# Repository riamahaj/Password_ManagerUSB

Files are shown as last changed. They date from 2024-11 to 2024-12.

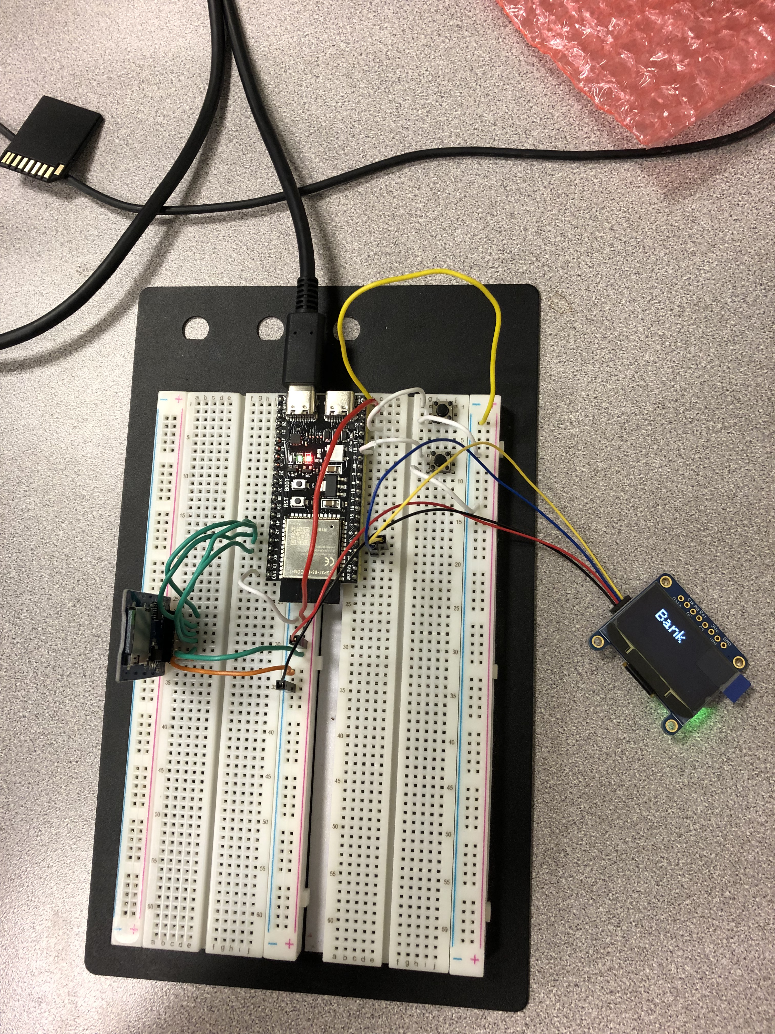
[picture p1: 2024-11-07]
breadboard-proto.jpg

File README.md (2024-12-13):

# Password_ManagerUSB
This repository is for our ECE 411 Password Manager Bank project
It features a MicroSD card reader, an OLED for displaying password websites, and a keypad for scrolling and selecting passwords to output. 
It has 32GB space for extra storage and has encryption features, as well as a webpage that displays websites and passwords with a password strength indicator.





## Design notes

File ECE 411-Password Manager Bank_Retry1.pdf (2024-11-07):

Untitled Gantt Project | Nov 7, 2024 http://

Project manager
Project dates | Oct 10, 2024 - Dec 14, 2024
Completion | 0%
Tasks | 35
Resources | 0

Name | Begin date | End date
1: Creating Project | 10/10/24 | 10/15/24
1.1 Generate 3-5 Project ideas | 10/10/24 | 10/12/24
1.2 Refine Project Ideas | 10/13/24 | 10/13/24
1.3 Select 1 Project | 10/14/24 | 10/14/24
1.4 Set Up a Collaboration Site | 10/14/24 | 10/14/24
1.5 Purchase Components | 10/15/24 | 10/15/24
2: Product Design Specification | 10/17/24 | 10/23/24
2.1 Setting Project Reqiuirements and Concept | 10/17/24 | 10/17/24
2.1 Level 0 and 1 Block Diagrams | 10/18/24 | 10/19/24
2.2 Design Specifications | 10/21/24 | 10/23/24
3: Prototype | 10/24/24 | 11/20/24
3.1 Design Matrix | 10/24/24 | 10/25/24
3.2 AHP Methodologies | 10/26/24 | 10/27/24
3.3 Connect OLED to ESP32 | 10/24/24 | 10/25/24
3.4 Connect MircoSD to ESP32 | 10/26/24 | 10/27/24
3.5 Add 2 buttons | 10/26/24 | 10/26/24
3.6 Preliminary Shematic(KiCAD) | 10/28/24 | 10/29/24
3.7 Test Components | 10/28/24 | 10/30/24
4: Software Implementation | 11/7/24 | 11/16/24
4.1 Read/Write .txt Files | 11/7/24 | 11/11/24
4.1.a Test/Debug | 11/7/24 | 11/11/24
4.2 Implement CVS Files | 11/12/24 | 11/16/24
4.2.a Test/Debug | 11/12/24 | 11/16/24
5. LED UI | 11/11/24 | 11/16/24
5.1 Create User Friendly Menu | 11/11/24 | 11/15/24
5.2 Add Optional Features(If Time permits) | 11/16/24 | 11/16/24
Untitled Gantt Project | Nov 7, 2024
Tasks | 2

Name | Begin date | End date
6: CAD | 11/15/24 | 11/20/24
6.1 Circuit Schemaitc | 11/15/24 | 11/19/24
6.2 Final CAD review | 11/20/24 | 11/20/24
7: Final Product | 11/21/24 | 12/13/24
7.1 Send Final Version of Schematic to EPL | 11/21/24 | 11/26/24
7.2 Pick up Circuit Board | 11/27/24 | 11/27/24
7.3 Assembling | 11/29/24 | 12/1/24
7.4 Test Boards | 12/2/24 | 12/6/24
7.4 Final Product Presentation | 12/9/24 | 12/13/24
Tasks | 3

## Gantt Chart

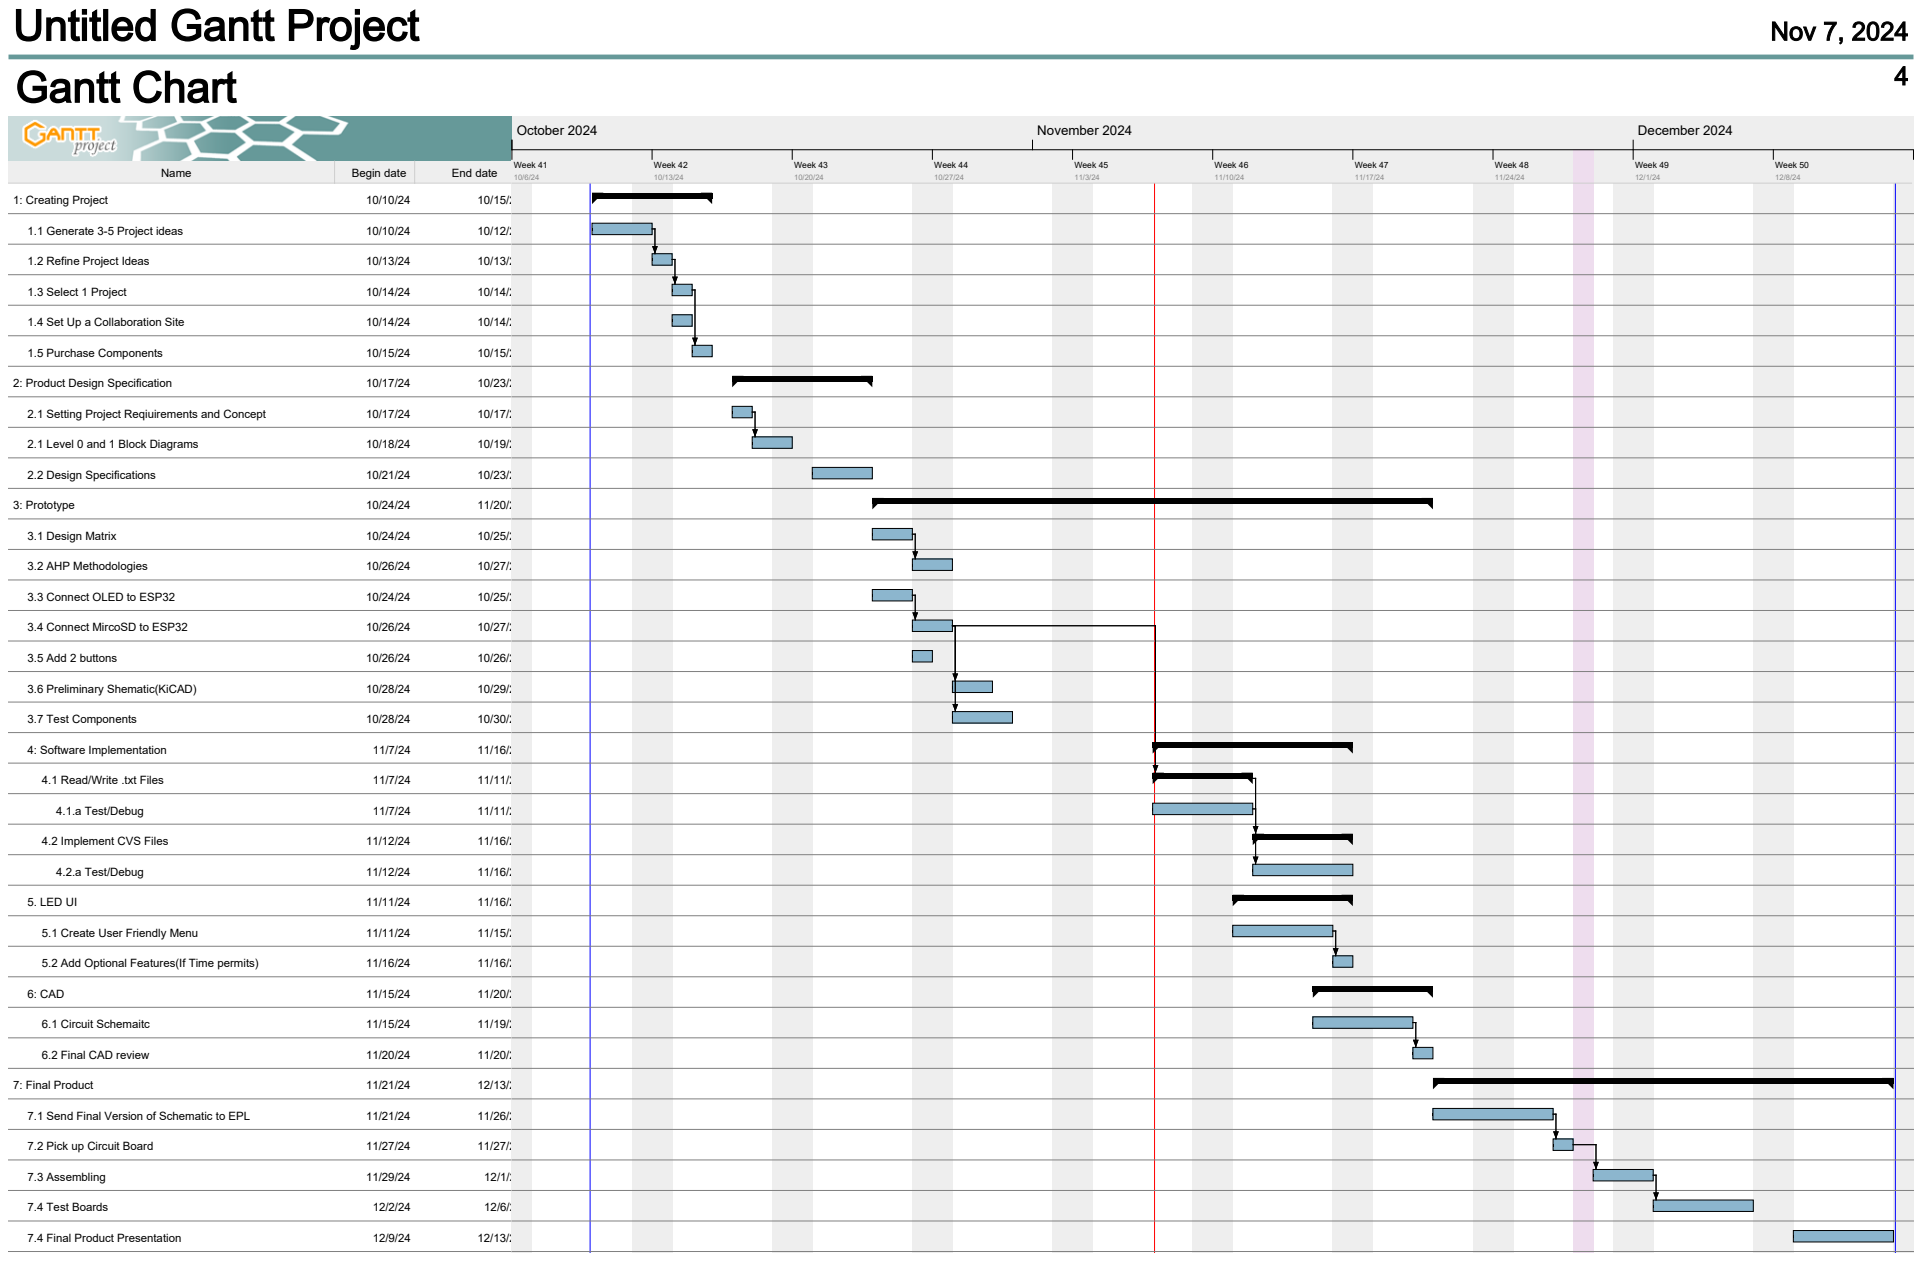
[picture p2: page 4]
Name; Begin date; End date; 1: Creating Project; 1.1 Generate 3-5 Project ideas; 1.2 Refine Project Ideas; 1.3 Select 1 Project; 1.4 Set Up a Collaboration Site; 1.5 Purchase Components; 2: Product Design Specification; 2.1 Setting Project Reqiuirements and Concept; 2.1 Level 0 and 1 Block Diagrams; 2.2 Design Specifications; 3: Prototype; 3.1 Design Matrix; 3.2 AHP Methodologies; 3.3 Connect OLED to ESP32; 3.4 Connect MircoSD to ESP32; 3.5 Add 2 buttons; 3.6 Preliminary Shematic(KiCAD)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

## Resources Chart

5

Name | Default role
October 2024 | November 2024 | December 2024
Week 41 | Week 42 | Week 43 | Week 44 | Week 45 | Week 46 | Week 47 | Week 48 | Week 49 | Week 50
10/6/24 | 10/13/24 | 10/20/24 | 10/27/24 | 11/3/24 | 11/10/24 | 11/17/24 | 11/24/24 | 12/1/24 | 12/8/24

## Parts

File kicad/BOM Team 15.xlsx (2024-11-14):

Bill Of Materials for: TEAM 15
Last modified: 11/13/2024
PCB version: 1
BOM revision: 3 |  | P/NP | = Place/Not Place (components marked NP are not stuffed on the board)
Cnt | Part References | P/NP | Mfg | Mfg PN | Description | Dist | Dist Part Number | Cost Ea. | Cost Total | URL/Source
1 | A1 | P | DORHEA | ESP32-S3-WROOM-1-N16R8 | ESP32-S3-DevKit N16R8 | Amazon | B0C9H7Y66W | $17.99 | $17.99 | Amazon (https://www.amazon.com/dp/B0CKXJLP4B?ref=ppx_yo2ov_dt_b_fed_asin_title&th=1)
1 | N/A | NP | JST | PHR-4 | JST PH 2mm Cable | Adafruit | 3950 | $1.50 | $1.50 | Adafruit (https://www.adafruit.com/product/3950)
1 | SW1, SW2, SW3, SW4 | P | Omron | B3F-1020 | Tactile button switch (6mm) (Pack of 20) | Adafruit | 367 | $0.12 | $2.50 | Adafruit (https://www.adafruit.com/product/367)
1 | N/A | NP | Univison Technology Inc. | UG-2864HSWEG01 | OLED Display (128x64) | Adafruit | 326 | $17.50 | $17.50 | Adafruit (https://www.adafruit.com/product/326)
1 | N/A | NP | Adafruit Industries | 254 | MicroSD Reader Module | Adafruit | ADA254 | $7.50 | $7.50 | Adafruit (https://www.adafruit.com/product/254)
1 | N/A | NP | California JOS | N/A | 40 PCS M2F SS Jumper Cable Pack | Amazon | B0BRTKTV64 | $3.99 | $3.99 | Amazon (https://www.amazon.com/California-JOS-Breadboard-Optional-Multicolored/dp/B0BRTHR2RL)
1 | J1 | P | Sullin Connector Solutions | PPTC041LFBN_RC | 4 Pin Header Female Socket | Digikey | S7037-ND | $0.56 | $0.56 | Digikey (https://www.digikey.com/en/products/detail/sullins-connector-solutions/PPPC041LFBN-RC/810176)
1 | J2 | P | Sullin Connector Solutions | PPTC061LFBN_RC | 6 Pin Header Female Socket | Digikey | S7004-ND | $0.61 | $0.61 | Digikey (https://www.digikey.com/en/products/detail/sullins-connector-solutions/PPTC061LFBN-RC/810145)
1 | N/A | NP | San Disk | SDSQUAR-032G-GN6MA | SanDisk Ultra microSD Card | Amazon | B073JWXGNT | $13.00 | $13.00 | Amazon (https://www.amazon.com/SanDisk-Ultra-microSDXC-Memory-Adapter/dp/B073JWXGNT)
 |  |  |  |  |  |  |  | TOTAL: | $65.15
VERSION INFO
Rev | Date | Notes
2 | 2024-11-13 | Inserted all parts, need to go over review
1 | 2020-11-12 | Initial BOM, most parts on here, havent filled out all PNs

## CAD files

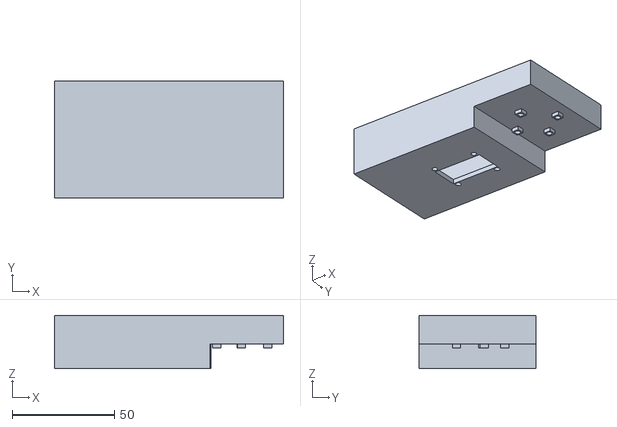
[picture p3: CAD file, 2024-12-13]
CAD/final_revision (5).STL
112.0 x 57.0 x 26.0

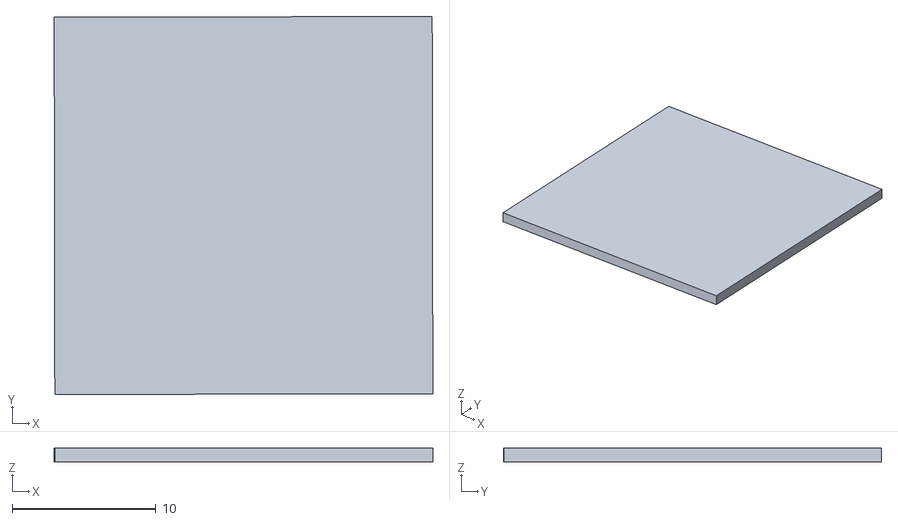
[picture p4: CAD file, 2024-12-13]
CAD/square_basr.STL
26.4 x 26.3 x 1.00

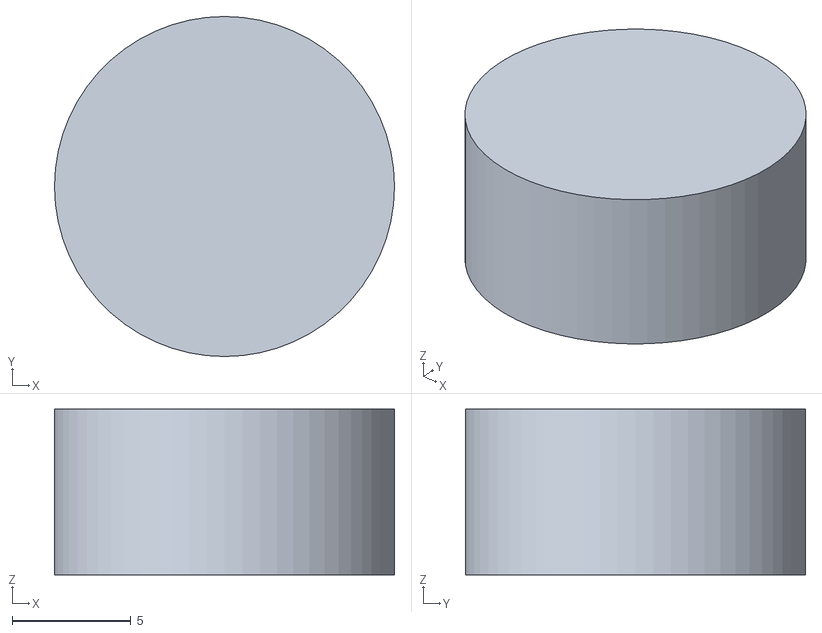
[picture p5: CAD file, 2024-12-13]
CAD/cylinders.STL
14.3 x 14.3 x 7.00

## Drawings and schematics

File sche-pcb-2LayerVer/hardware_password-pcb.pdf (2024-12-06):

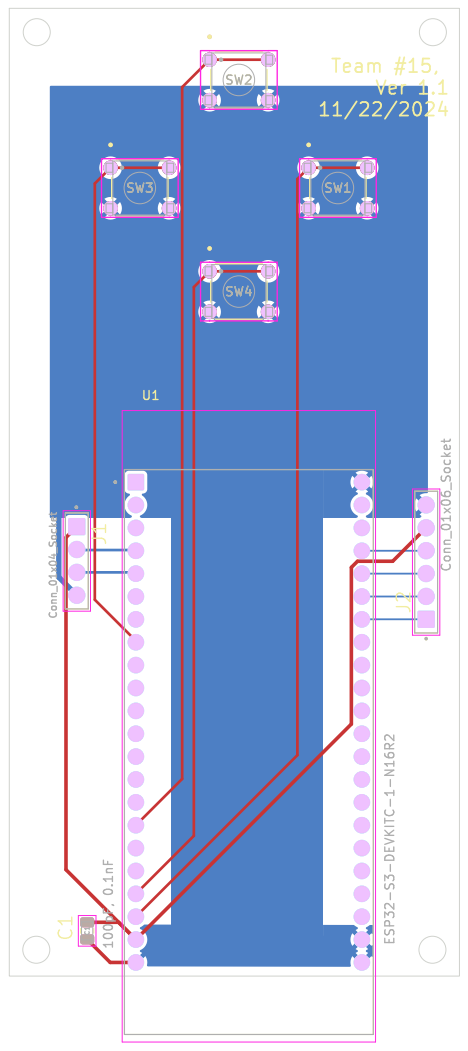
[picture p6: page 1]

Id: 1/1 Title: File: hardware_password.kicad_pcb Sheet:

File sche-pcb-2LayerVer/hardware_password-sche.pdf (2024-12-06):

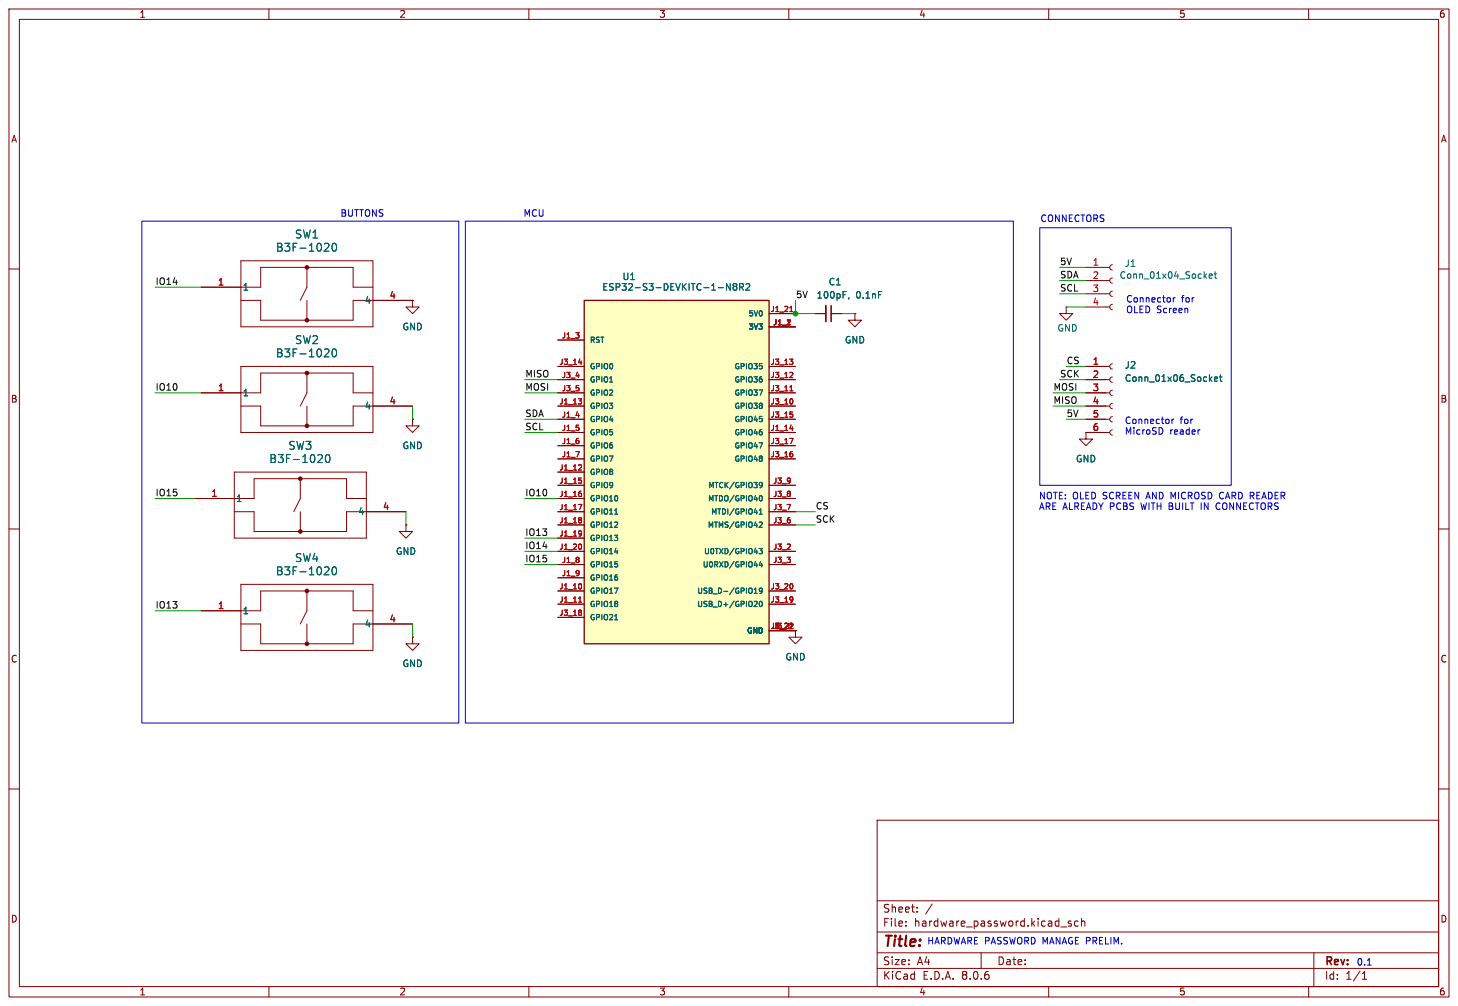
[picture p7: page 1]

5V MOSI HARDWARE PASSWORD MANAGE PRELIM. NOTE: OLED SCREEN AND MICROSD CARD READER

ARE ALREADY PCBS WITH BUILT IN CONNECTORS

Id: 1/1 Title: File: hardware_password.kicad_sch Sheet: /

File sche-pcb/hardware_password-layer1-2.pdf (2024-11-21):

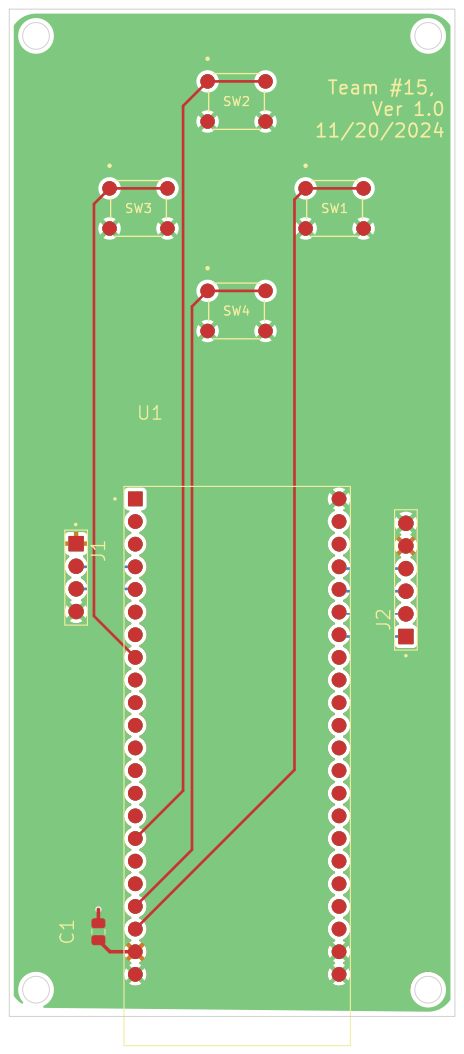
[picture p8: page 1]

Id: 1/1 Title: File: hardware_password.kicad_pcb Sheet:

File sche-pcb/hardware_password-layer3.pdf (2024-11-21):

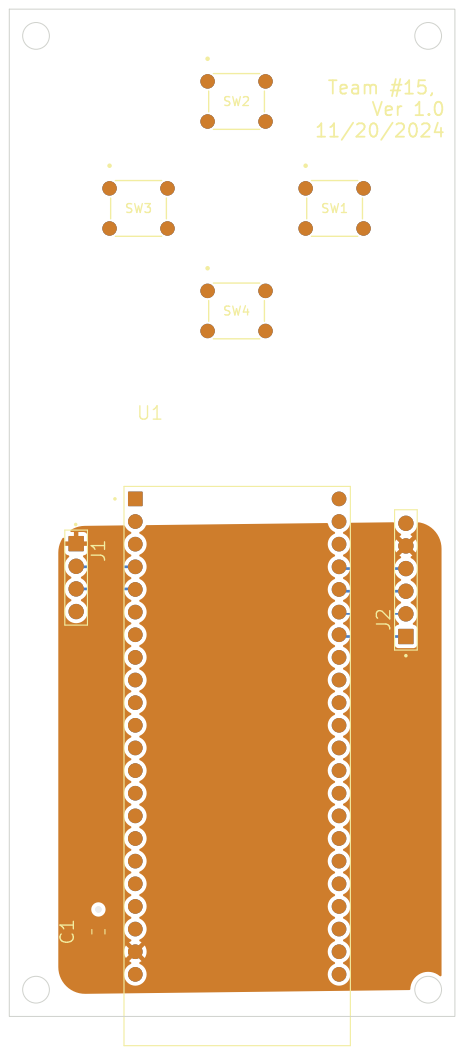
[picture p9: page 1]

Id: 1/1 Title: File: hardware_password.kicad_pcb Sheet:

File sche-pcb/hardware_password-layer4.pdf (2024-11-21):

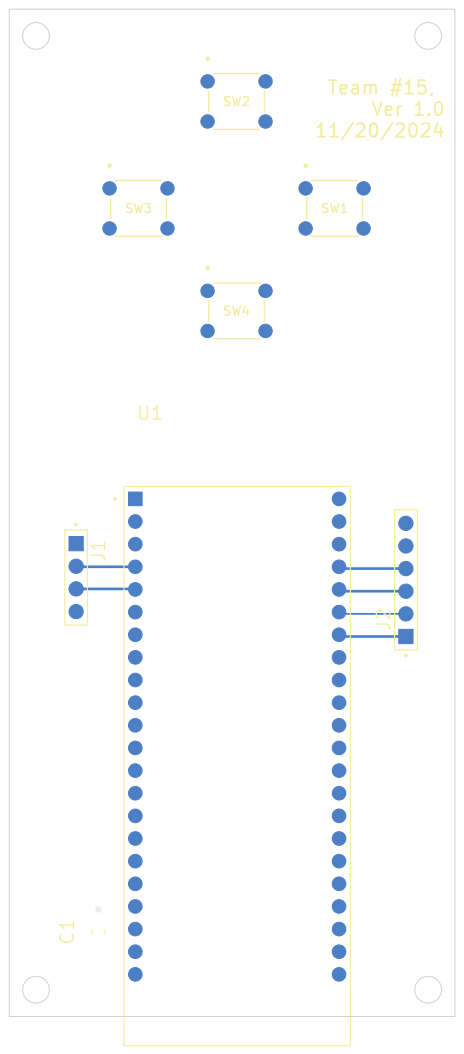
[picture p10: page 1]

Id: 1/1 Title: File: hardware_password.kicad_pcb Sheet:

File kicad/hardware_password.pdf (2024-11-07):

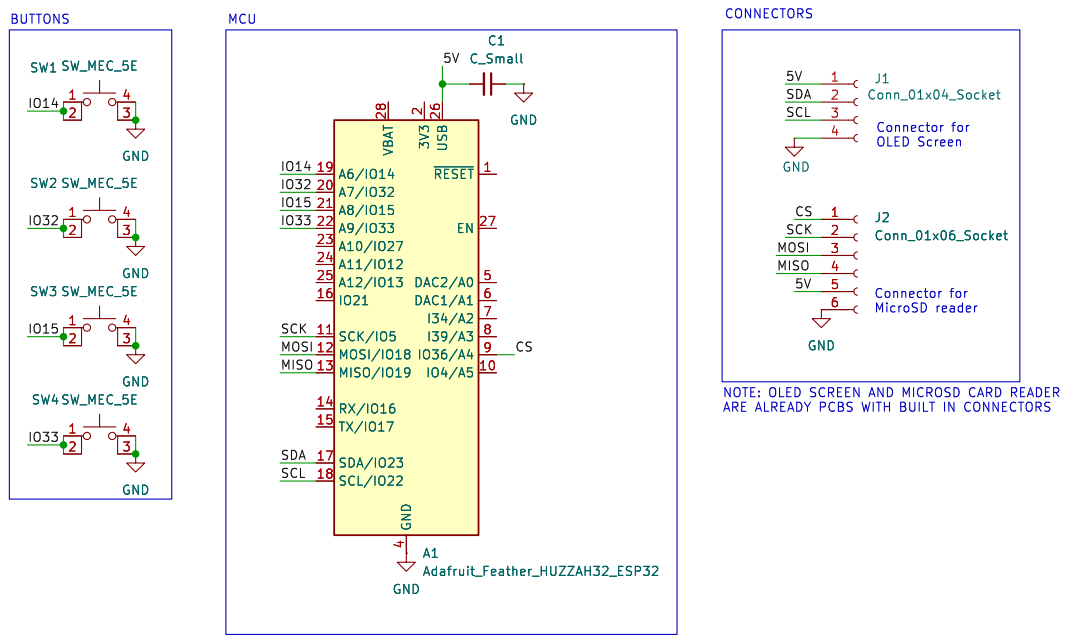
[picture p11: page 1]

2 A7/IO32 20 A8/IO15 21 A9/IO33 22 A10/IO27 23 A11/IO12 24 A12/IO13 25 USB 26 EN 27 VBAT 28 GND

Id: 1/1 Title: File: hardware_password.kicad_sch Sheet: / GND

NOTE: OLED SCREEN AND MICROSD CARD READER

HARDWARE PASSWORD MANAGE PRELIM.

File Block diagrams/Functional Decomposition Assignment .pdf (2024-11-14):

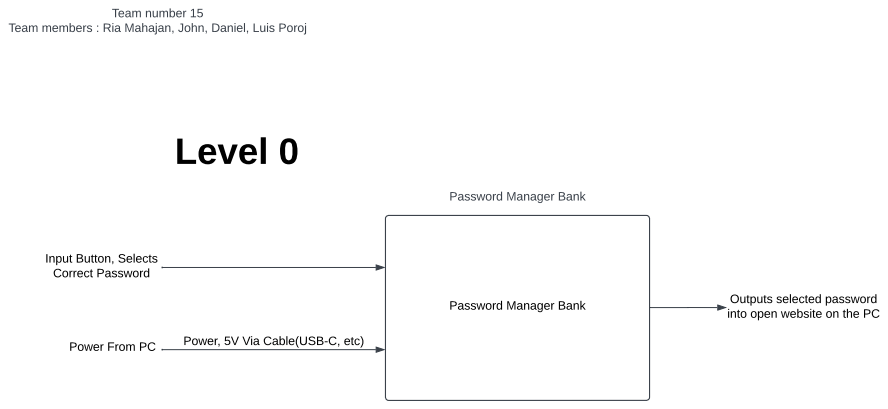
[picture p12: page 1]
Level 0; Team number 15

Team members : Ria Mahajan, John, Daniel, Luis Poroj

Password Manager Bank

Input Button, Selects
Correct Password

Outputs selected password
into open website on the PC

Power From PC

Power, 5V Via Cable(USB-C, etc)

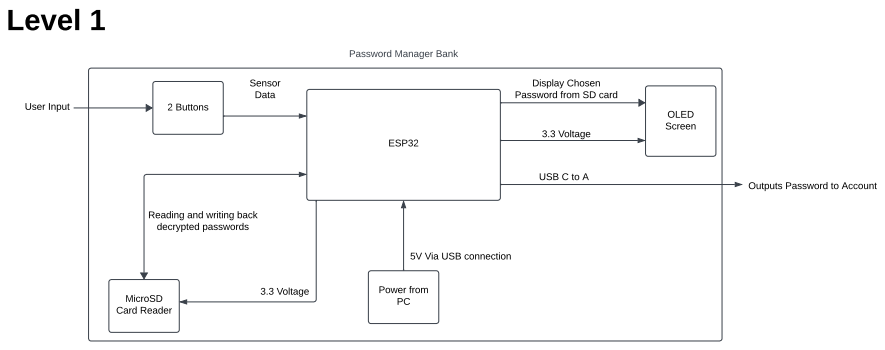
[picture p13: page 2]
ESP32; OLED Screen; 2 Buttons; 3.3 Voltage; User Input; MicroSD Card Reader; Power from PC; Level 1; Sensor Data; USB C to A

Password Manager Bank

Display Chosen Password from SD card

Outputs Password to Account

Reading and writing back
decrypted passwords

5V Via USB connection

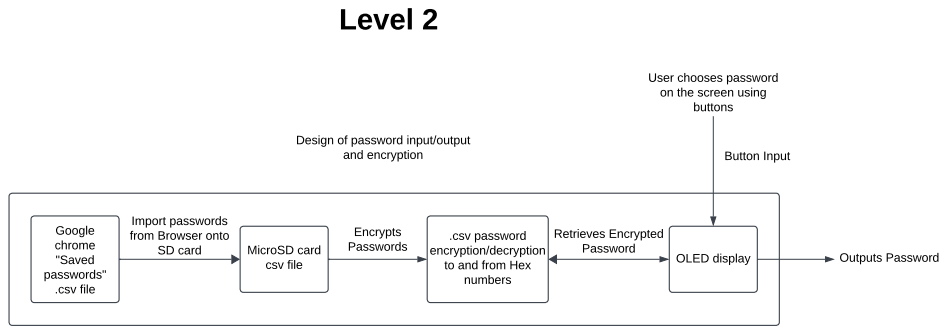
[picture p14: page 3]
Level 2; and encryption; MicroSD card; csv file; OLED display; Button Input; Outputs Password; Retrieves Encrypted Password; Encrypts Passwords; Google chrome "Saved passwords" .csv file

User chooses password
on the screen using
buttons

Design of password input/output

Import passwords
from Browser onto
SD card

.csv password
encryption/decryption
to and from Hex
numbers

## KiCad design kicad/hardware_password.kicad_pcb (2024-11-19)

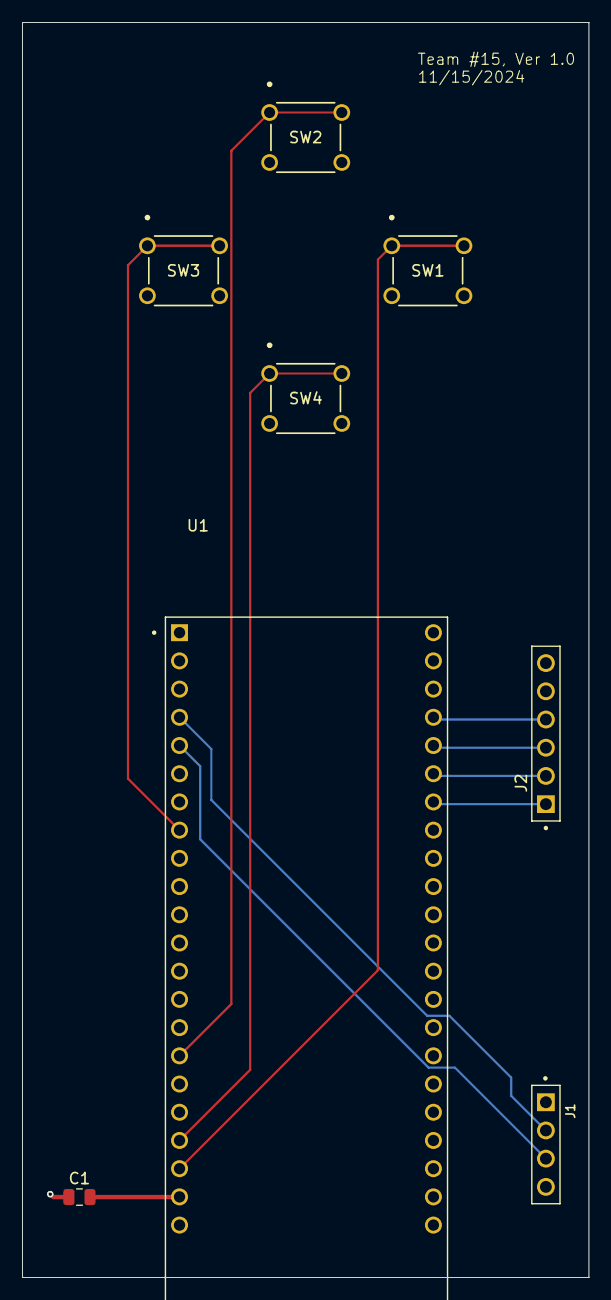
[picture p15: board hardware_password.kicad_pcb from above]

Board: 4 copper layers, 51.0 x 113.0 mm, 8 parts (0 on the bottom side), 13 nets.

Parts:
C1: 100pF, 0.1nF; C_0805_2012Metric
J1: Conn_01x04_Socket; SULLINS_PPTC041LFBN-RC
J2: Conn_01x06_Socket; SULLINS_PPTC061LFBN-RC
SW1, SW2, SW3, SW4: B3F-1020; SW_B3F-1000_OMR
U1: ESP32-S3-DEVKITC-1-N8R2; XCVR_ESP32-S3-DEVKITC-1-N8R2

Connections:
/5V: C1.2, J1.1, J2.5, U1.J1_21 (5V0)
/CS: J2.1, U1.J3_7 (MTDI/GPIO41)
/IO10: SW2.1, SW2.2, U1.J1_16 (GPIO10)
/IO13: SW4.1, SW4.2, U1.J1_19 (GPIO13)
/IO14: SW1.1, SW1.2, U1.J1_20 (GPIO14)
/IO15: SW3.1, SW3.2, U1.J1_8 (GPIO15)
/MISO: J2.4, U1.J3_4 (GPIO1)
/MOSI: J2.3, U1.J3_5 (GPIO2)
/SCK: J2.2, U1.J3_6 (MTMS/GPIO42)
/SCL: J1.3, U1.J1_5 (GPIO5)
/SDA: J1.2, U1.J1_4 (GPIO4)
GND: C1.1, J1.4, J2.6, SW1.3, SW1.4, SW2.3, SW2.4, SW3.3, SW3.4, SW4.3, SW4.4, U1.J1_22 (GND), U1.J3_1 (GND), U1.J3_21 (GND), U1.J3_22 (GND)
unnamed: U1.J1_1 (3V3), U1.J1_2 (3V3)

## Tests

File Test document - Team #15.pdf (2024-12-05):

PART 1

UNIT TESTS

1. Power - check that everything is on
a. Measure the 5V pin on the ESP32-S3
b. Make sure that USB-C port powers the ESP32-S3
2. Sensor - buttons
a. Test if the a button press can affect the OLED display
b. Test if the ESP32-S3 can register a button press and release
3. Actuator - OLED
a. Test if the OLED can output an image
b. Test that the I2C protocol is communicating properly
c. Test if the OLED can change images with a button press
4. microSD Card Reader
a. Test if a file in the microSD card can store at least 10 passwords
b. Test if files are readable from the microSD card
c. Test if file are writable from the microSD card
5. ESP32-S3
a. Test that the GPIO pins can input and output data

VERIFICATION
6. Test the PCB to make that traces are routed correctly
7. Two buttons must be able to switch between passwords
8. OLED display must be able to display different names
9. microSD card reader must be able to read a CSV file
10. microSD card reader should to able to read the encrypted password file
11. The ESP32-S3 should identify as a keyboard
12. The ESP32-S3 should navigate the password file sequentially
2023-11-28 | Page 1 of 5

Validation
13. Must output and enter a password into a text field via button press
14. The SD card should store more than 10 passwords
15. The password manager device must fit into a pocket
16. Must input password through the UI
17. UI must display passwords and websites

Example Test Case

Test Author: John Yang
Test Case Name: | microSD card reading test | Test ID #: | 1
Description: | Test if the ESP32-S3 is capable of decrypting a file from the microSD card. This tests mainly if passwords can be correctly stored and outputted to the OLED display. | Type: | □ white box X black box □ ________

Tester Information
| Name of Tester: | John Yang | Date: | 12/3/24
| HW/SW Version: | 1.0 | Time: | 5PM
| Setup: | Needs a fully assembled device with an encrypted password file.
S T E P | Action | Expected Result | P A S S | F A I L | N / A | Comments
1 | Encryption | CSV will have encrypted hex passwords | X
2 | Reading | ESP32-S3 should have loaded encrypted file to memory | X
3 | Selecting password | Websites will be displayed on the OLED | X
4 | Decryption | Password will output on the website on the PC. Correct website name should be outputted to the OLED display. | X

5
6
7
8
9
| Overall test result: | | X | | | Repeat until password file exhausted

Example Matrix Test (for varying parameters)

Test Author: Ria

Test Case Name: | Maximum number of passwords | Test ID #: | 2
Description: | What is the maximum number of passwords we can input in the SD card | Type: | □ white box X black box □ _____________

Tester Information

| Name of Tester: | John Yang | Date: | 12/4/24
| HW/SW Version: | 1.0 | Time: | 7:33PM
| Setup: | Needs a fully assembled device with an encrypted password file. 5 encrypted password files will need to be created.
T E S T | INPUTS (# of Passwords) | EXPECTED OUTPUTS | P A S S | F A I L | N / A | Comments
1 | 0 | N/A | X
2 | 1 | Stores and outputs password: “password1” | X
3 | 3 | Stores and outputs “password1” to “password3” | X
4 | 10 | “password1” to “password10” | X
5 | 15 | “password1” to “password15” | X
6 | 25 | “password1” to “password25” | X
| Overall test result: | | X | | | Also outputs title on OLED screen

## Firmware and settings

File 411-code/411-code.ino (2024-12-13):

#include "functions.h"
#include <CSV_Parser.h>
#include <Adafruit_GFX.h>
#include <Adafruit_SSD1306.h>
#include <Bounce2.h>
#include "SimpleArduinoEncryption.h"
#include <SPI.h>
#include "SD.h"

#ifndef ARDUINO_USB_MODE
#error This ESP32 SoC has no Native USB interface
#elif ARDUINO_USB_MODE == 1
#warning This sketch should be used when USB is in OTG mode
void setup() {}
void loop() {}
#else

#include "USB.h"
#include "USBHIDKeyboard.h"
USBHIDKeyboard Keyboard;

File csvFile;

//struct to hold name and password
struct name_password{
  char *Name;
  char *password;
};

typedef struct name_password Struct;


// Encryption keys
const byte ENCRYPTION_KEYS[] = {0xAA, 0xBB, 0xCC, 0xCB};
const size_t NUM_KEYS = sizeof(ENCRYPTION_KEYS) / sizeof(ENCRYPTION_KEYS[0]);

// Initialize encryption object with keys
SimpleArduinoEncryption encryption(ENCRYPTION_KEYS, NUM_KEYS);

CSV_Parser en(/*format*/ "s", /*has_header*/ false);
CSV_Parser de(/*format*/ "s--s-", /*has_header*/ false);

// INSTANTIATE A Button OBJECT FROM THE Bounce2 NAMESPACE
Bounce2::Button button1 = Bounce2::Button();
Bounce2::Button button2 = Bounce2::Button();
Bounce2::Button button3 = Bounce2::Button();
Bounce2::Button button4 = Bounce2::Button();

char **en_hex;
char **Name;
char **password;

extern int buttonPin1;
extern int buttonPin2;
extern int buttonPin3;
extern int buttonPin4;

extern Adafruit_SSD1306 display;


Struct result;



Struct decrypt_display(char *encryptedHex, int row)
{ 
  Struct s;

  // Calculate buffer length and allocate memory
  size_t length = strlen(encryptedHex) / 2;
  byte message[length + 1];

  // Convert hexadecimal string to bytes
  SimpleArduinoEncryption::hexToBytes(encryptedHex, message, length);

  // Print encrypted data in hex format
  Serial.print("Encrypted String (Hex): ");
  SimpleArduinoEncryption::printHex(message, length);

  // Decrypt the message
  encryption.decrypt((char*)message);
  String decryptedString = String((char*)message);

  Serial.print("Decrypted String: ");
  Serial.println(decryptedString);

  de << decryptedString;
  de.parseLeftover();

  //set 0th column as name, 3th column as password
  Name = (char**)de[0];
  password = (char**)de[3];

  s.Name = Name[row];
  s.password = password[row];
  return s;
}

void setup() {
  // put your setup code here, to run once:
  Serial.begin(9600);
  
  setup_sd();
  
  button1.attach(buttonPin1 ,INPUT_PULLUP ); 
  button2.attach(buttonPin2 ,INPUT_PULLUP ); 
  button3.attach(buttonPin3, INPUT_PULLUP);
  button4.attach(buttonPin4, INPUT_PULLUP);
  
  // DEBOUNCE INTERVAL IN MILLISECONDS
  button1.interval(10);
  button2.interval(5); 
  button3.interval(10);
  button4.interval(10);
  
  // INDICATE THAT THE LOW STATE CORRESPONDS TO PHYSICALLY PRESSING THE BUTTON
  button1.setPressedState(LOW); 
  button2.setPressedState(LOW);
  button3.setPressedState(LOW);
  button4.setPressedState(LOW);
  
  Keyboard.begin();
  USB.begin();

  setup_screen(); 

    // Open the CSV file for reading
  csvFile = SD.open("/encrypt_pass.csv", FILE_READ);

    // Temporary storage for processed lines
  String newContent = "";
  
  while (csvFile.available()) {
    // Read a line from the CSV file
    String line = csvFile.readStringUntil('\n');

    // Check if the line contains any character values
    if (containsCharacter(line)) {
      // Encrypt the line
      String encryptedLine = encryptLine(line);
      newContent += encryptedLine + "\n"; // Append the encrypted line
    } else {
      // If no character, keep the line as is
      newContent += line + "\n";
    }
  }

  csvFile.close();

  // Reopen the file for writing
  csvFile = SD.open("/encrypt_pass.csv", FILE_WRITE);

  // Write the updated content back to the file
  csvFile.print(newContent);
  csvFile.close();

  Serial.println("File processing complete.");


  //csv parser will read the encrypted file and store it internally in one "block"
  if (en.readSDfile("/encrypt_pass.csv")) {
    
    en_hex=(char**)en[0];

    
    // output parsed values (allows to check that the file was parsed correctly)
    en.print(); // assumes that "Serial.begin()" was called before (otherwise it won't work)
    
  } else {
  Serial.println("ERROR: File called '/file.csv' does not exist...");
  }
  
  display.fillScreen(SSD1306_WHITE);
  display.display();
}
// button variables
int buttonState1;         // variable for reading the pushbutton status
int buttonState2;
int lastState1 = LOW;

int counter = 0;
int i = 0;

void loop() {

  // read the state of the pushbutton value:
  button1.update();
  button2.update();
  button3.update();
  button4.update();

  // check if the pushbutton is pressed. If it is, the buttonState is LOW:
  if (button1.pressed()) {
    //button pressed
    //increment name/password field in CSV file
    Serial.println("button press");
    result = decrypt_display(en_hex[counter],counter);

    if (counter < en.getRowsCount()-1 && counter >= 0)
    {
      ++counter;
    }
    else {
      counter = 0;
    }
  }
  
  else
  {
    //display.clearDisplay();
    display.setTextSize(2);
    display.setTextColor(SSD1306_WHITE);
    display.setCursor(20,10);
    display.setTextSize(2);
    display.println(result.Name);
    show();
    Serial.println(result.Name);
  }
  
    
  if (button2.pressed()){
    //button2 pressed
    //output the password field to PC
    Keyboard.print(result.password);
    delay(25);
    Keyboard.write(KEY_RETURN);
  }
  
  //increment row by 5
  if (button3.pressed())
  {
    Serial.println("button press");

    if (counter < en.getRowsCount()-1 && counter >= 0)
    {
      counter = counter + 2;
    }
    else {
      counter = 0;
    }
    result = decrypt_display(en_hex[counter],counter);
  }
  //decrement row
  if (button4.pressed())
  {
    Serial.println("button press");

    if (counter < en.getRowsCount()-1 && counter > 0)
    {
      counter = counter - 1;
    }
    else {
      counter = 0;
    }
    result = decrypt_display(en_hex[counter],counter);
  }
  
}
//checks if there are characters in the line
bool containsCharacter(const String &line) {
  for (size_t i = 0; i < line.length(); i++) {
    char c = line[i];
    // Check if the character is alphabetic but not a valid hexadecimal character
    if (isAlpha(c) && !isHexadecimalDigit(c)) {
      return true;
    }
  }
  return false;
}

// Helper function to check if a character is a valid hexadecimal digit
bool isHexadecimalDigit(char c) {
  return (c >= '0' && c <= '9') || (c >= 'A' && c <= 'F') || (c >= 'a' && c <= 'f');
}

// Placeholder encryption function
String encryptLine(String messageString) {
  // String to encrypt
  Serial.print("Original String: ");
  Serial.println(messageString);

  // Convert String to char array
  size_t length = messageString.length();
  char message[length + 1];
  messageString.toCharArray(message, sizeof(message));

  // Encrypt message
  encryption.encrypt(message);

  // Convert encrypted byte array to hexadecimal string
  char hexStr[length * 2 + 1];
  SimpleArduinoEncryption::bytesToHex((const byte*)message, length, hexStr);

  Serial.print("Encrypted String (Hex): ");
  Serial.println(hexStr);

  return hexStr;
}
#endif

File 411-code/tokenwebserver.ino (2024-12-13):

#include <WiFi.h>
#include <ESPAsyncWebServer.h>
#include <SD.h>
#include <SPI.h>

const char* ssid = "ria";
const char* password = "irbx4738";

// Define the token for authentication
const String validToken = "your_token_here";

String websites[10];
String passwords[10];

// Initialize SD card pins
int sck = 42;
int miso = 1;
int mosi = 2;
int cs = 41;

// Create an AsyncWebServer object on port 80
AsyncWebServer server(80);

// Password strength calculation function
String calculatePasswordStrength(const String& password) {
  int n = password.length();
  int strength = 0;
  String strengthDisplay = "";
  
  // Define character categories
  bool hasLower = false, hasUpper = false;
  bool hasNum = false, specialChar = false;
  String normalChars = "abcdefghijklmnopqrstuvwxyzABCDEFGHIJKLMNOPQRSTUVWXYZ1234567890 ";

  // Check character types in the password
  for (int i = 0; i < n; i++) {
    if (islower(password[i])) hasLower = true;
    if (isupper(password[i])) hasUpper = true;
    if (isdigit(password[i])) hasNum = true;

    // Check for special characters
    if (normalChars.indexOf(password[i]) == -1) { // if character is not in the normalChars string
      specialChar = true;
    }
  }

  // Score password strength based on criteria
  if (n >= 12) strength += 1;
  if (n >= 16) strength += 1;
  if (hasLower) strength += 1;
  if (hasUpper) strength += 1;
  if (specialChar) strength += 1;
  if (hasNum) strength += 1;

  // Determine password strength rating (stars)
  for (int i = 0; i < strength; ++i)
    strengthDisplay += "*";

  return strengthDisplay;
}

// This function loads a CSV file from the SD card, extracts the website names, passwords, and strength, and formats it as HTML
String loadCSV() {
  File file = SD.open("/data.csv");  // Open the file from SD card
  String csvContent = "<html><body><h2>Website Passwords</h2><table border='1' style='width:80%; margin:auto; border-collapse: collapse; text-align:left;'>"
                      "<tr><th>Website</th><th>Password</th><th>Strength</th></tr>";

  if (file) {
    bool firstLine = true;
    while (file.available()) {
      String line = file.readStringUntil('\n');
      
      // Skip the first line (header)
      if (firstLine) {
        firstLine = false;
        continue;
      }

      // Parse the line by splitting it by commas
      int commaIndex1 = line.indexOf(',');
      int commaIndex2 = line.indexOf(',', commaIndex1 + 1);
      int commaIndex3 = line.indexOf(',', commaIndex2 + 1);
      
      if (commaIndex1 > 0 && commaIndex2 > 0 && commaIndex3 > 0) {
        String website = line.substring(0, commaIndex1);    // The 'name' column
        String password = line.substring(commaIndex3 + 1);  // The 'password' column
        String strength = calculatePasswordStrength(password); // Calculate the password strength
        
        // Add each website, password, and strength to the HTML table
        csvContent += "<tr><td>" + website + "</td><td>" + password + "</td><td>" + strength + "</td></tr>";
      }
    }
    file.close();
  }
  
  csvContent += "</table></body></html>";
  return csvContent;
}

// Update password in CSV file on SD card
void updateCSVFile() {
  File file = SD.open("/data.csv", FILE_WRITE);  
  if (file) {
    file.println("website,url,username,password");  // Add header again
    for (int i = 0; i < 10; i++) {
      if (websites[i] != "") {
        file.print(websites[i] + ",www." + websites[i] + ",user," + passwords[i]);
        file.println();
      }
    }
    file.close();
  }
}

// Function to handle authentication
bool isValidToken(AsyncWebServerRequest *request) {
  // Check if token is present as a query parameter
  if (request->hasParam("token")) {
    String token = request->getParam("token")->value();
    return token == validToken;
  }
  return false;
}

void setup() {
  // Start Serial Monitor
  Serial.begin(115200);

  // Connect to Wi-Fi
  WiFi.begin(ssid, password);
  while (WiFi.status() != WL_CONNECTED) {
    delay(500);
    Serial.println("Connecting to WiFi...");
  }
  Serial.println("Connected to WiFi");
  SPI.begin(sck, miso, mosi, cs);

  // Initialize SD card
  if (!SD.begin(cs)) {
    Serial.println("SD card initialization failed!");
    return;
  }
  Serial.println("SD card initialized.");

  // Serve the CSV content at the root URL
  server.on("/", HTTP_GET, [](AsyncWebServerRequest *request){
    if (isValidToken(request)) {
      // If token is valid, send the CSV content
      String htmlContent = loadCSV();  // Load CSV data and convert it to HTML
      request->send(200, "text/html", htmlContent);
    } else {
      // If token is invalid, return an error message
      request->send(403, "text/plain", "Forbidden: Invalid Token");
    }
  });

  // Handle password update request
  server.on("/update", HTTP_POST, [](AsyncWebServerRequest *request){
    if (isValidToken(request)) {
      String index = request->getParam("index")->value();
      String new_password = request->getParam("new_password")->value();
      
      int idx = index.toInt();
      
      if (idx >= 0 && idx < 10) {
        passwords[idx] = new_password;  // Update the password in the array
        
        // Update the CSV file with the new password
        updateCSVFile();
        
        request->send(200, "text/html", "<html><body>Password updated successfully! <a href='/'>Back</a></body></html>");
      } else {
        request->send(400, "text/plain", "Invalid index");
      }
    } else {
      request->send(403, "text/plain", "Forbidden: Invalid Token");
    }
  });
  
  // Start the server
  server.begin();
}

void loop() {
  // Nothing to do here for this web server
}

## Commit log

2024-11-07 Create kicad
2024-11-15 Added decryption/encryption
    Features to be added:
    security measure to unlock device
    way to add passwords to csv file
2024-11-19 moved power planes to inner layers
    [hardware_password.kicad_pcb]
2024-12-13 Update 411-code.ino
    My added code is encased in comment lines in case it breaks stuff
2024-12-13 case CAD
    [cylinders.STL, final_revision (5).STL, square_basr.STL]
